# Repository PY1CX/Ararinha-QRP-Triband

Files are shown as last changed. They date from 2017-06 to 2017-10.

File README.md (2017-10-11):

# Ararinha-QRP-Triband

This is a PCB for the Ararinha 6 project from Miguel PY2OHH, made with a 4 layer board. 

You can find the correct values of the BPF for 40/20/15m bands on the RFSim99 files in the repository.

### Already tested in the project prototype:
* IF
* Microphone Pre-Amplifier
* LM386 Audio Output
* XTAL Filter
* BPF for 40m and 15m - Tested on MiniVNA Tiny

### Note on current version of the board:

* RF Switching: I found that the MASWSS0136TR is a better RF Switch for the project than the one in the PCB, going for it. Less expensive and doesn't have the 50 ohm termination that could ruin the project impedances.  

* RF transistors: I started building the project with 2n3904 but I'm going to switch to the 2SC4915 that are in use in newer radios and have better specifications on RF. Decided on them because I wanna beat the record for Ararinha design, using it on 15m and later on 
6m band. (As 21/09/2017, testing it with the 2sc4915 looking good and no parasitic oscillation found yet)

* LM386 amplifier circuit: There is a missing electrolytic capacitor between the LM386 pin 5 and the Headphone output. Can be any capacitor from 10uf to 470uf with at least 16v.

* The 78L05's on the V1.0 board has pin 1 and pin 3 changed. Corrected on V2.0 schematic

* 4:1 xformer is inverted in both RF Mixer and RF Pre sheets. Needs to be corrected. In V1.0 you can just rotate it 180 degrees.

* R32 (2k2 resistor on RF Pre) is wrong placed, just replace it with a 0R resistor for V1.0 board

* CWKey isn't routed to any connector

### A 3D preview of the 4 layer board for the Ararinha 6 Project
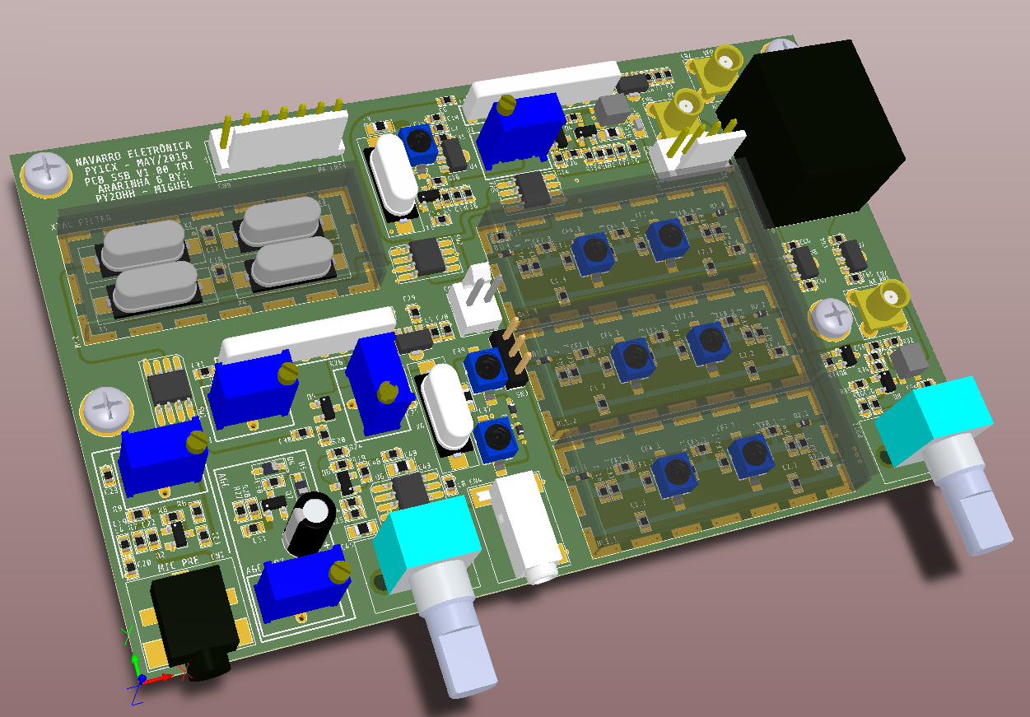
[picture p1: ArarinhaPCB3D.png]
Preview


It's free to copy or modify and uses the Beerware License ( https://en.wikipedia.org/wiki/Beerware )

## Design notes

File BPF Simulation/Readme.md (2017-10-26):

# Band Pass Filter Simulation

Here you find the BPF Simulation files for 40m (7Mhz), 20m (14Mhz) and 15m (21Mhz).

The simulation was done on RFSim99, you can find RFSim99 easily on Google and it's very easy to use and simulate things.

Also there is the testing of the 40m and 15m Band Pass Filters for the project with MiniVNA

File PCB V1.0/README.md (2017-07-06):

# Ararinha QRP Triband

This folder contains all the files of the Version 1.0 of the PCB done. To order V1.0 PCBs just submit your Gerber to one online PCB service or e-mail me I still have some laying around.

### A 3D preview of the 4 layer board for the Ararinha 6 Project V1.0
Preview

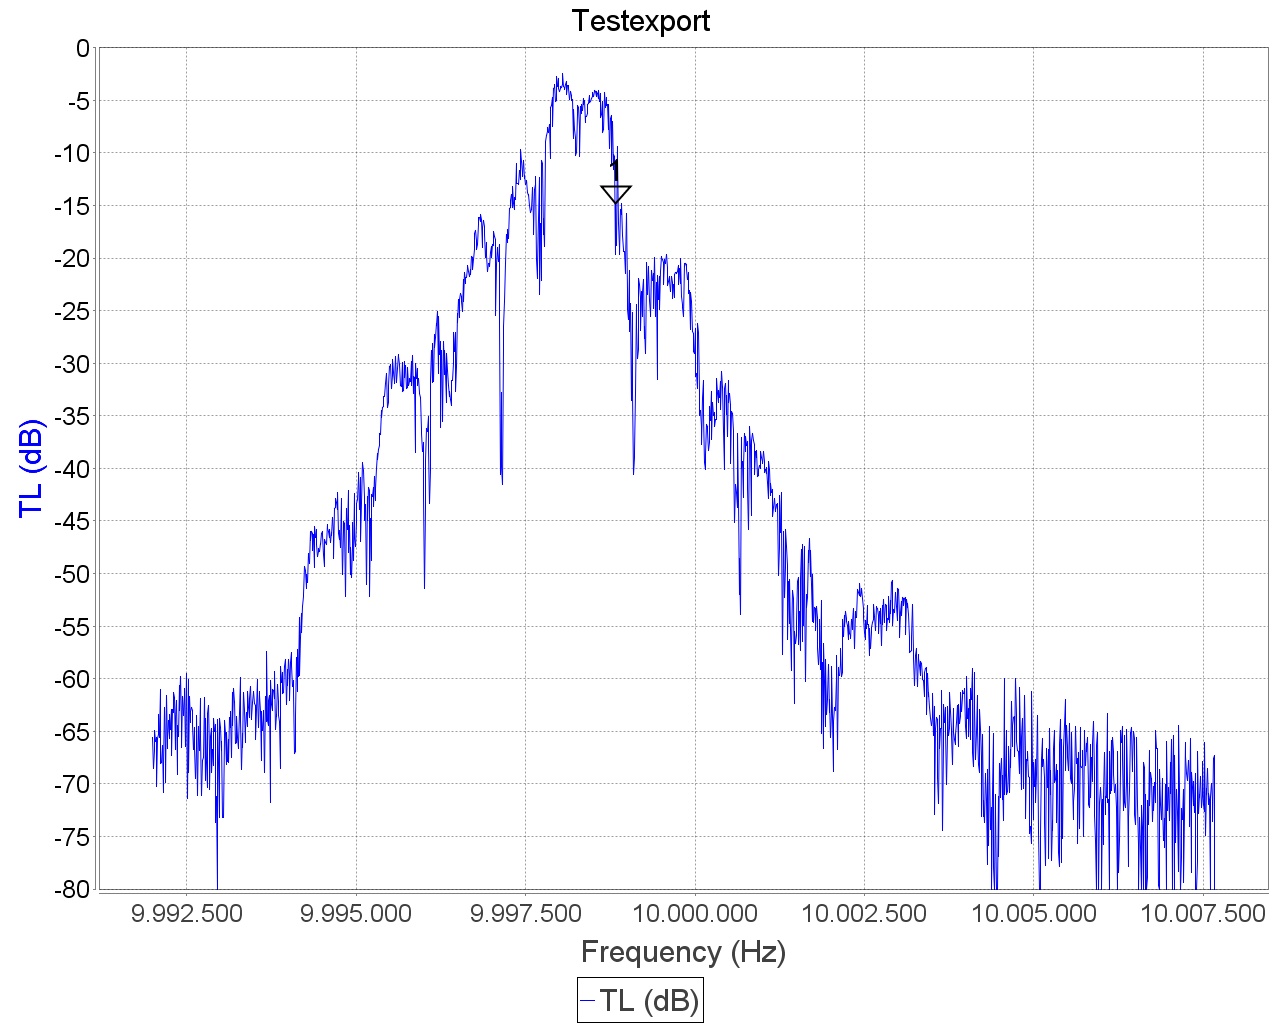
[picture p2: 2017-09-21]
Images/VNA_170921_031100.jpg

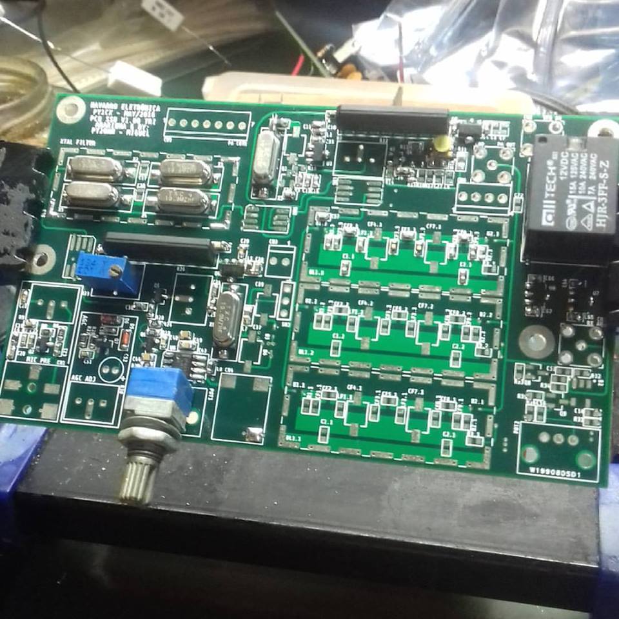
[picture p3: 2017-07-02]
Images/BPF-IF-Xtal.jpg

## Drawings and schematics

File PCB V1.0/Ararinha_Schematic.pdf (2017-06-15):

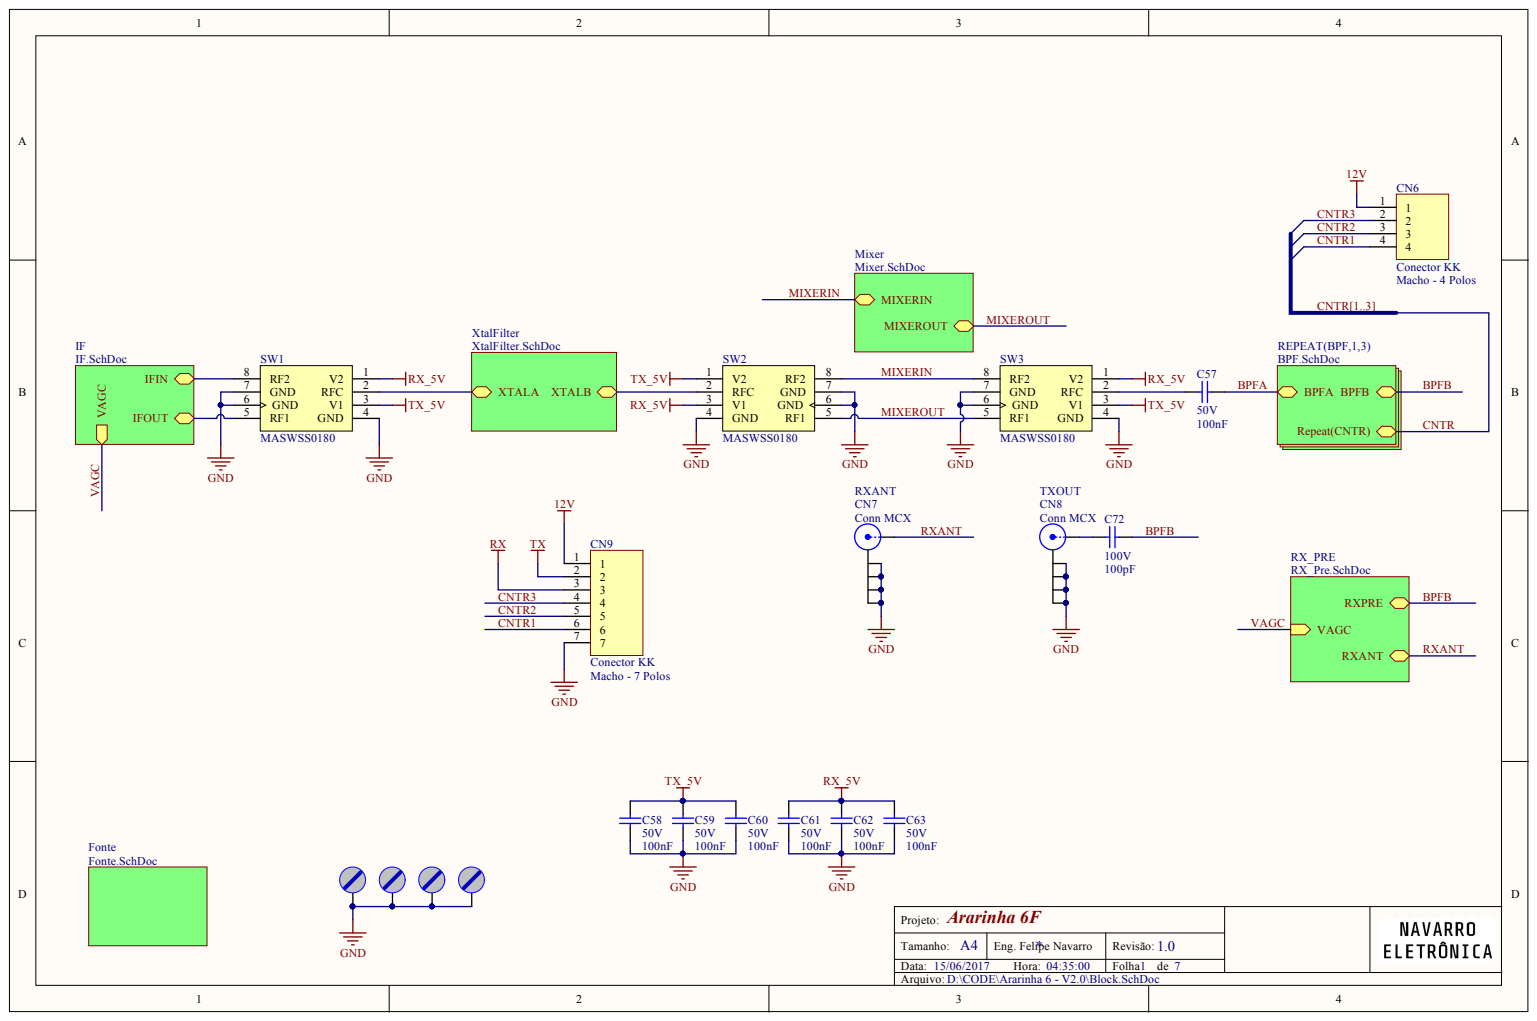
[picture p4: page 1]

Ararinha 6F Projeto:

Tamanho: A4 | Eng. Felipe Navarro * | Revisão: 1.0

Data: 15/06/2017 Hora: 04:35:00 | | Folha de

D:\CODE\Ararinha 6 - V2.0\Block.SchDoc

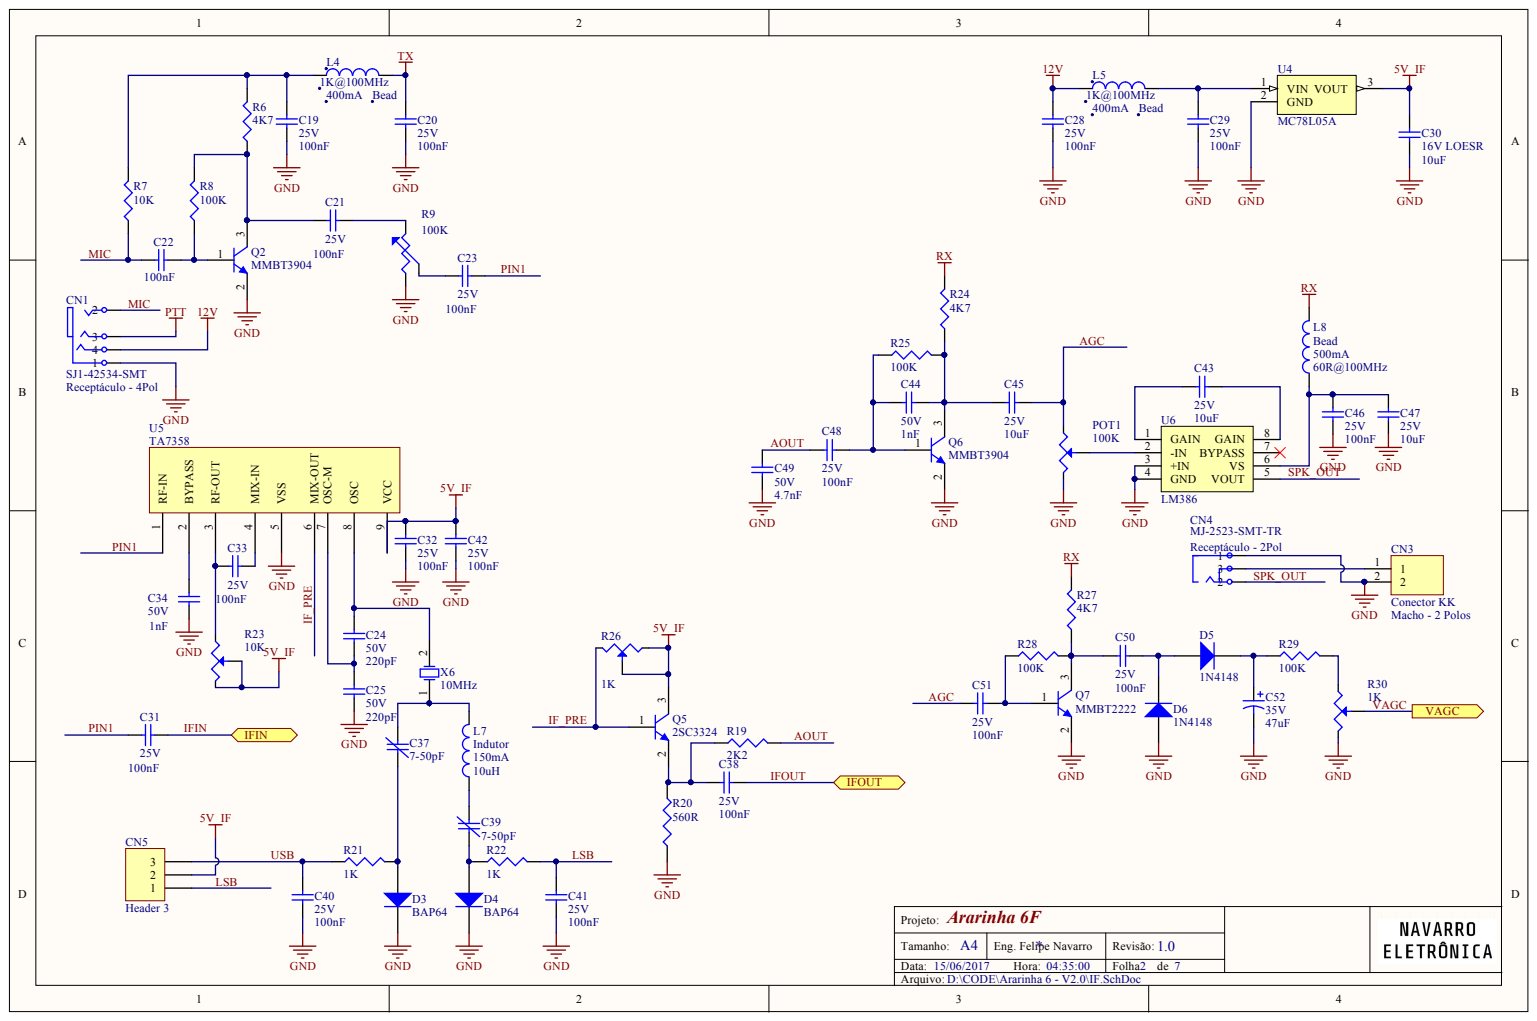
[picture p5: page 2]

GAIN 1
-IN 2 BYPASS VS | 7
+IN 3 | 6

Ararinha 6F Projeto:

Tamanho: A4 | Eng. Felipe Navarro * | Revisão: 1.0

D:\CODE\Ararinha 6 - V2.0\IF.SchDoc

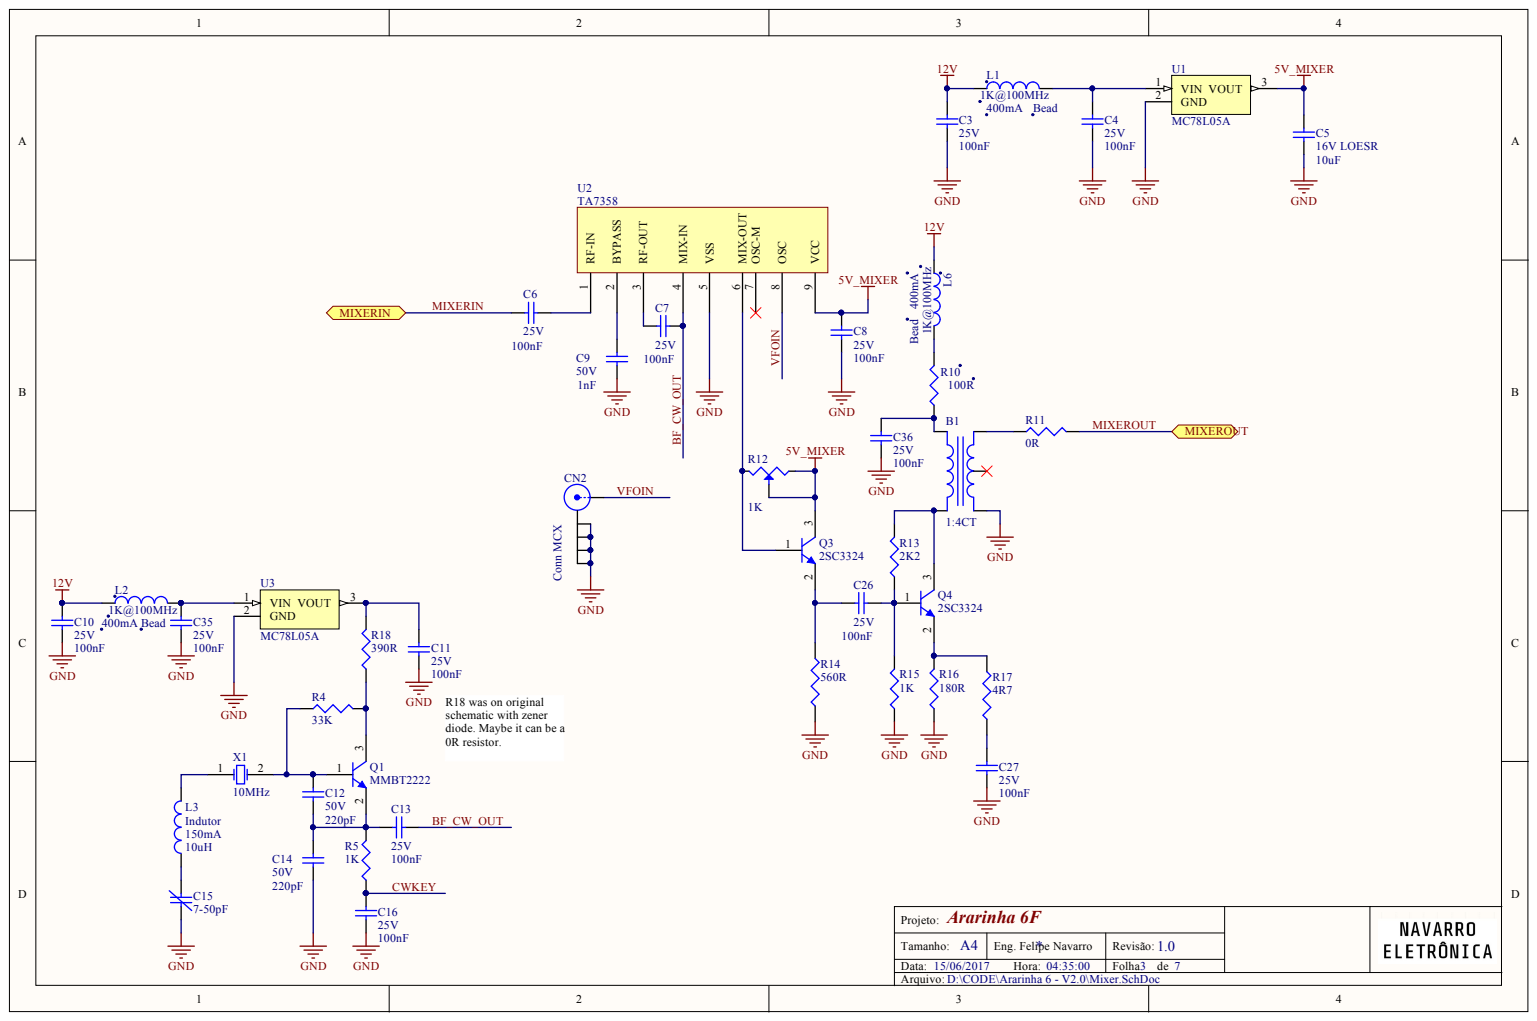
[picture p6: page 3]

R18 was on original
schematic with zener
diode. Maybe it can be a
0R resistor.

Ararinha 6F Projeto:

Tamanho: A4 | Eng. Felipe Navarro * | Revisão: 1.0

D:\CODE\Ararinha 6 - V2.0\Mixer.SchDoc

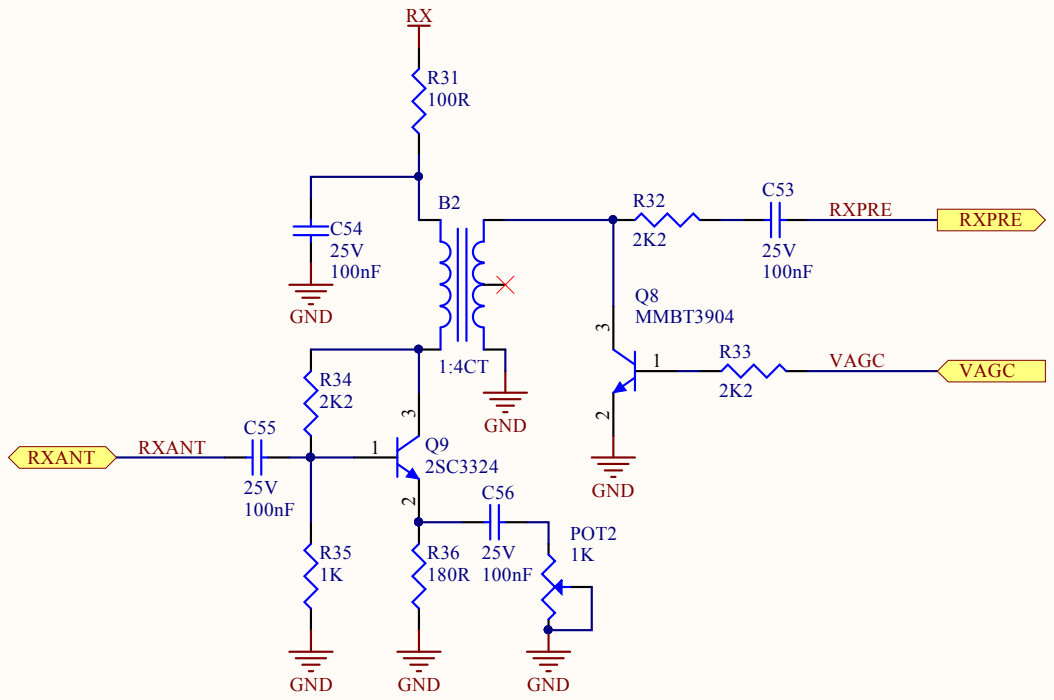
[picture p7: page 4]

Ararinha 6F Projeto:

Tamanho: A4 | Eng. Felipe Navarro * | Revisão: 1.0

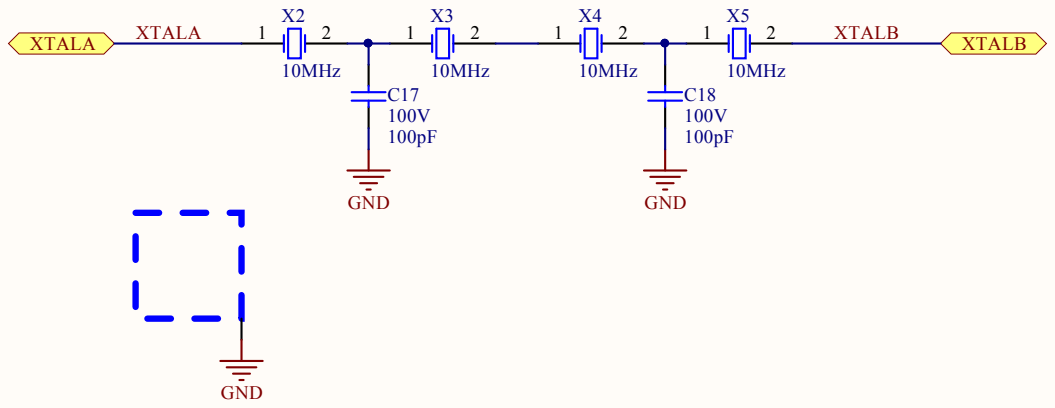
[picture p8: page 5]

Ararinha 6F Projeto:

Tamanho: A4 | Eng. Felipe Navarro * | Revisão: 1.0

D:\CODE\Ararinha 6 - V2.0\XtalFilter.SchDoc

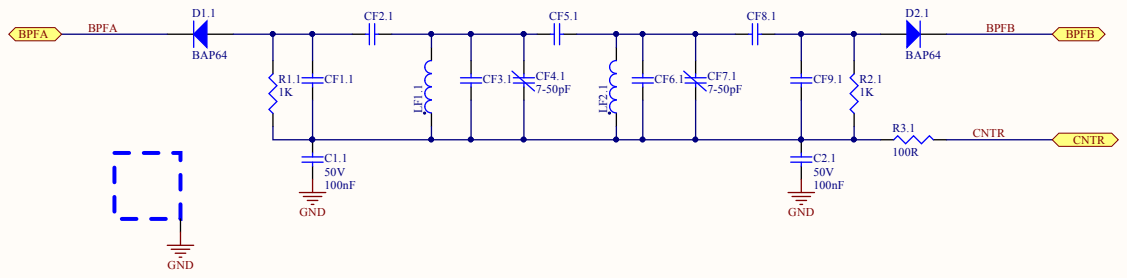
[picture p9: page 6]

Ararinha 6F Projeto:

Tamanho: A4 | Eng. Felipe Navarro * | Revisão: 1.0

D:\CODE\Ararinha 6 - V2.0\BPF.SchDoc

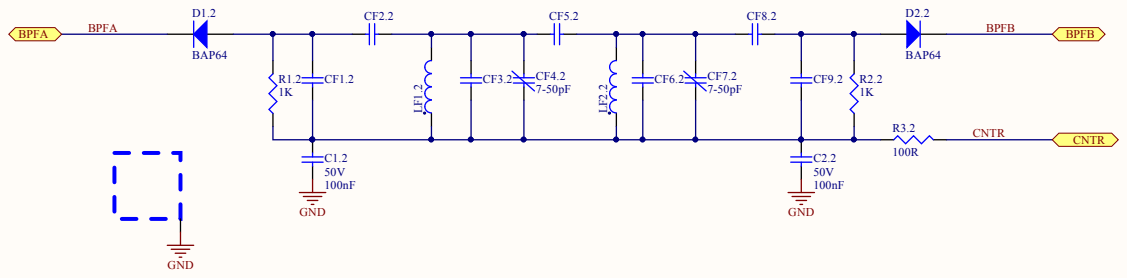
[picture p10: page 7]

Ararinha 6F Projeto:

Tamanho: A4 | Eng. Felipe Navarro * | Revisão: 1.0

D:\CODE\Ararinha 6 - V2.0\BPF.SchDoc

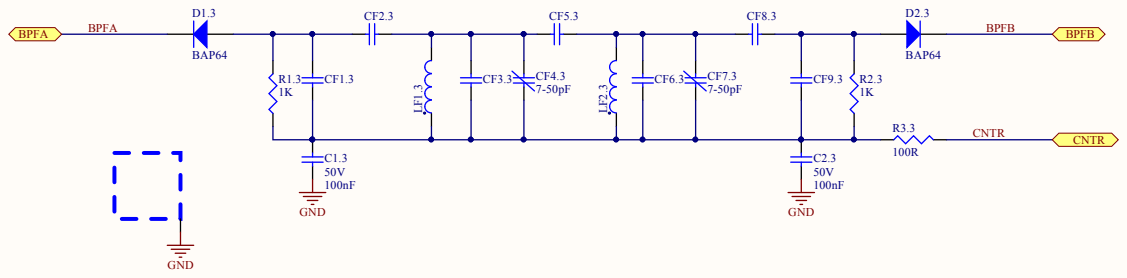
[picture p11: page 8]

Ararinha 6F Projeto:

Tamanho: A4 | Eng. Felipe Navarro * | Revisão: 1.0

D:\CODE\Ararinha 6 - V2.0\BPF.SchDoc

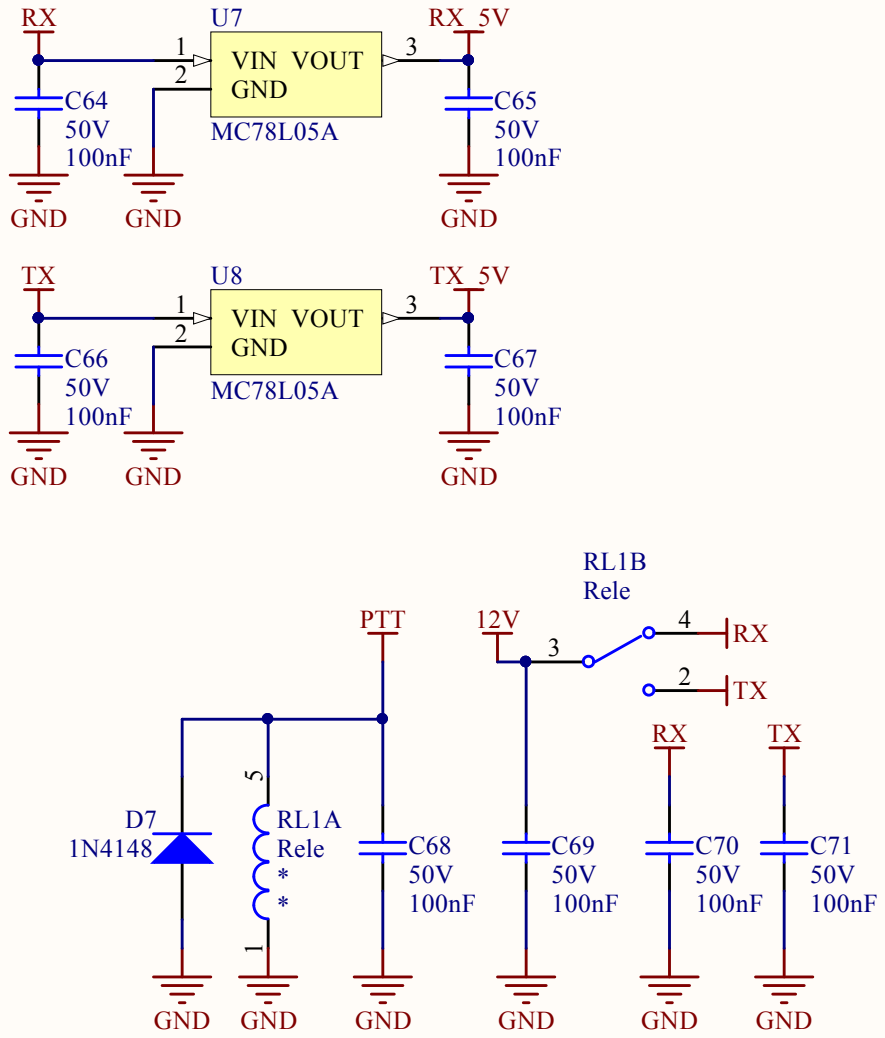
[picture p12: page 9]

Ararinha 6F Projeto:

Tamanho: A4 | Eng. Felipe Navarro * | Revisão: 1.0

D:\CODE\Ararinha 6 - V2.0\Fonte.SchDoc

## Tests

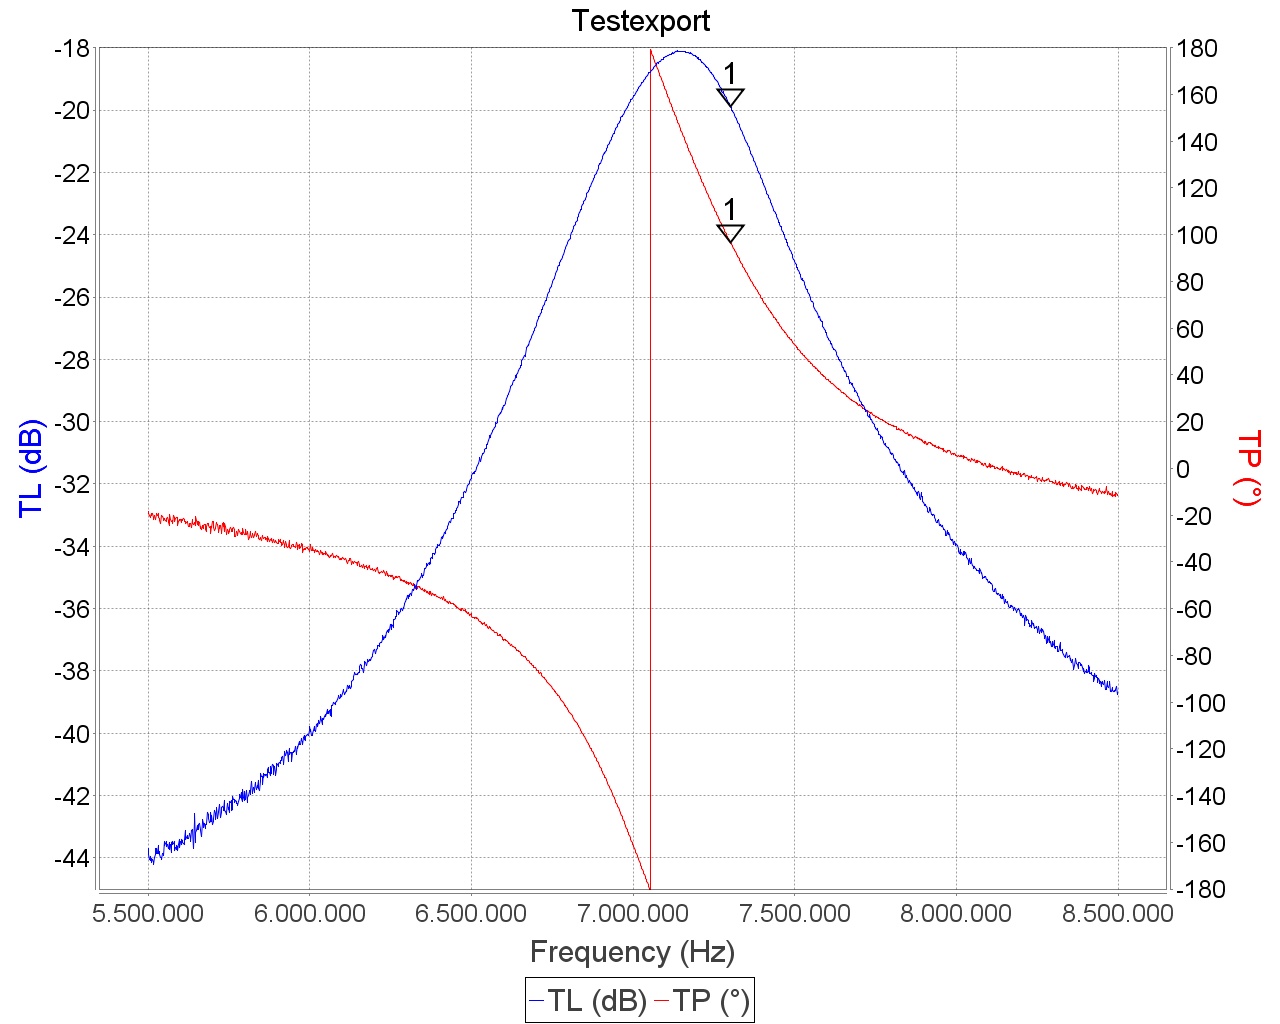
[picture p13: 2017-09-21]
BPF Simulation/40M BPF Test with VNA.jpg

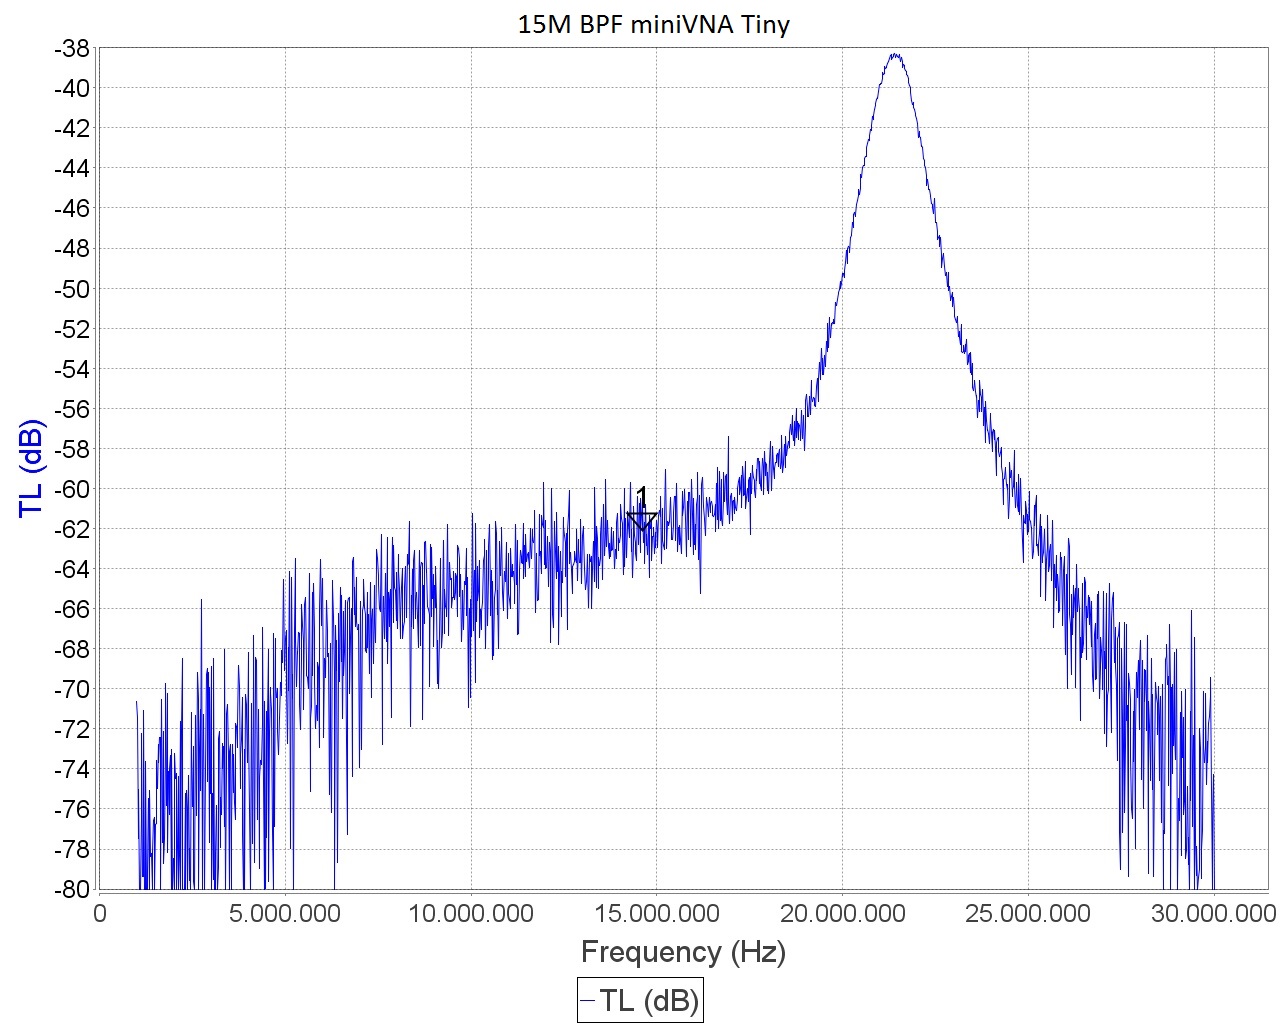
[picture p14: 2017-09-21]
BPF Simulation/15M BPF Test with VNA.jpg

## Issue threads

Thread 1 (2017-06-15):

LM386 Capacitor

PY1CX, 2017-06-15:
There is a missing capacitor on the LM386 circuit for the V1.0 of the board.
You need to cut the trace between the Headphone output jacket and the LM386 pin 5. Put a capacitor of at least 16v from 10uF to 470uF.

Closed 2017-06-15.

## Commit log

2016-07-19 Push PCB Document
    [Ararinha_PCB.PcbDoc, Ararinha_PCB.PrjPcb, BPF.SchDoc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]
2016-07-19 Final Schematic PDF
    Final schematic PDF
2017-06-14 Added a 3D view of the PCB
2017-06-15 LM386 output capacitor note
2017-06-15 Schematic PCB
    Old schematic was not well organized so we did a clean up to people easily understand.
2017-06-15 Lastest version of 1.0 PCB with cosmetic review
    Did some cosmetic review of the schematic files.
    [Ararinha_PCB.PcbDoc, Ararinha_PCB.PrjPcb, BPF.SchDoc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]
2017-06-15 LOG isn't necessary when using git
    LOG isn't necessary when using git
    [LOG.SchDoc]
2017-06-23 Gerber Files
2017-06-24 Final commit of V1.0 board
    From now we're going to work on the V2.0 board and file the bug report for this version here. Corrections will be on the V2.0
    [Ararinha_PCB.PcbDoc, Ararinha_PCB.PrjPcb, BPF.SchDoc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]
2017-06-26 Final V1.0 Schematic
2017-07-06 3D Vision of V1.0 Board
2017-07-06 Added C73 in LM386 Output
    [IF.SchDoc]
2017-07-07 Bug Fixes and start of V2.0
    [Ararinha_PCB.PrjPcb, BPF.SchDoc, Block.SchDoc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]
2017-07-18 Working on V2 PCB
    [Ararinha_PCB.PcbDoc]
2017-07-18 Work on V2 PCB
    [Ararinha_PCB.PcbDoc]
2017-07-19 PCB V2.0
    [Ararinha_PCB.PcbDoc]
2017-08-19 LM78L05 corrected
    [Fonte.SchDoc, IF.SchDoc, Mixer.SchDoc]
2017-09-21 Crystal Filter test
    Besides doesn't selected the xtals for the xtal filter, it looks good for me!
